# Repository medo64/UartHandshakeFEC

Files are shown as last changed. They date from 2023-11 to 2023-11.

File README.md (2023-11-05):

[UART w/Handshake Framework Expansion Card](https://medo64.com/uarthandshakefec/)
=================================================================================

This Framework laptop expansion card will show up on your system as a serial
device and allow for a non-isolated serial UART communication up to 3 Mbaud
baud rate with all handshake signals exposed.

Please note that this card is not using RS-232 but TTL (either 3.3V or 5V)
voltage levels (depending on the solder-jumper position).

## UART Pinout

To connect to this board, one has to use a 7-pin JST XH connector. The following
table represents the pinout, pin 1 being on the left as looking into the
expansion card.

| # | Ref  | Description |
|--:|:----:|---|
| 1 | CTS# | Clear To Send Control Input |
| 2 | DSR# | Data Set Ready Control Input |
| 3 | RXD  | Receiving  Data Input. |
| 4 | GND  | Ground supply |
| 5 | TXD  | Transmit Data Output |
| 6 | DTR# | Data Terminal Ready Control Output |
| 7 | RTS# | Request to Send Control Output |

As power consumption is low, wires can be almost any AWG. I would recommend
using 24 AWG wire 0.25 mm² as they allow for greater compatibility with other
connectors.

## Supported Speeds

This board employs the FT232R as its UART chip, and consequently, it supports
all the baud rates this chip [can handle](https://ftdichip.com/Documents/AppNotes/AN232B-05_BaudRates.pdf).
The table below lists the standard baud rates.

| Baud rate | Actual | Error | Divisor |
|---:|---:|---:|---:|
| 300 | 300 | 0.00% |  10000.000 |
| 600 | 600 | 0.00% | 5000.000 |
| 1,200 | 1,200 | 0.00% | 2500.000 |
| 1,800 | 1,800 | 0.00% | 1666.625 |
| 2,400 | 2,400 | 0.00% | 1250.000 |
| 4,800 | 4,800 | 0.00% | 625.000 |
| 7,200 | 7,201 | 0.01% | 416.625 |
| 9,600 | 9,600 | 0.00% | 312.500 |
| 14,400 | 14,406 | 0.04% | 208.250 |
| 19,200 | 19,200 | 0.00% | 156.250 |
| 28,800 | 28,812 | 0.04% | 104.125 |
| 38,400 | 38,400 | 0.00% | 78.125 |
| 57,600 | 57,692 | 0.16% | 52.000 |
| 115,200 | 115,385 | 0.16% | 26.000 |
| 230,400 | 230,769 | 0.16% | 13.000 |
| 460,800 | 461,538 | 0.16% | 6.500 |
| 921,600 | 923,077 | 0.16% | 3.250 |
| 1,000,000 | 1,000,000 | 0.00% | 3.000 |

While the UART chip does support baud rates up to 3 Mbaud, granularity of such
rates is severely limited.

---
*You can check my blog and other projects at [www.medo64.com](https://www.medo64.com/electronics/).*

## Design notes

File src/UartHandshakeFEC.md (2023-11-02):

### UartHandshakeFEC Parts

|  # | Part | RefDes  | Preferred Part Number |
|---:|---|---|---|
|  1 | C 10nF X7R 16V (0805) | C1 | 399-17617-1-ND |
|  2 | C 100nF X7R 16V (0805) | C2-C3 | 478-5311-1-ND |
|  1 | C 4.7uF X5R 16V (0805) | C4 | 1276-1244-1-ND |
|  3 | D TVS 5V SM05T1G (SOT23-3) | D1-D3 | SM05T1GOSCT-ND |
|  2 | DS LED (0805) | DS1-DS2 | 475-1415-1-ND |
|  1 | J JST XH Vertical (7w) | J1 | 455-B7B-XH-A-ND |
|  1 | L Ferrite 600R@100Mhz | L1 | 240-2390-1-ND |
|  2 | R 1K 0.125W (0805) | R1-R2 | RMCF0805FT1K00CT-ND |
|  1 | R 5.1K 0.125W (0805) | R3 | RMCF0805FT5K10CT-ND |
|  1 | U Transciever Uart FT232R (SSOP-28) | U1 | 768-FT232RNL-TUBE-ND |

#### Board Size

| | Dimensions | Area | Thickness |
|---|---|---|---|
| PCB |  24.0 x 27.9 mm | 1.1 in² | 0.8 mm |

#### FTDI Configuration

| Setting | Value  |
|---|---|
| CBUS0 | TXLED# |
| CBUS1 | RXLED# |
| CBUS2 | TXDEN  |
| CBUS3 | PWREN# |
| CBUS4 | SLEEP# |

#### Power

| Property | Value  |
|---|---:|
| Voltage  | 5 V |
| Current  |  90 mA |

#### Jumpers

##### 3V3

This jumper has to be bridged for operation in 3.3V. If this jumper is bridged,
5V jumper MUST NOT be bridged too.

##### 5V

This jumper has to be bridged for operation in 5V. If this jumper is bridged,
3.3V jumper MUST NOT be bridged too.

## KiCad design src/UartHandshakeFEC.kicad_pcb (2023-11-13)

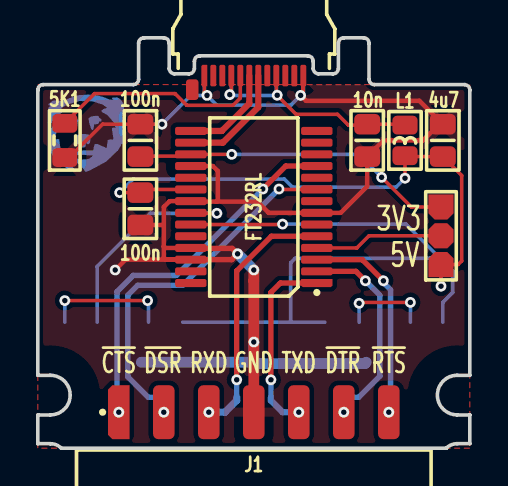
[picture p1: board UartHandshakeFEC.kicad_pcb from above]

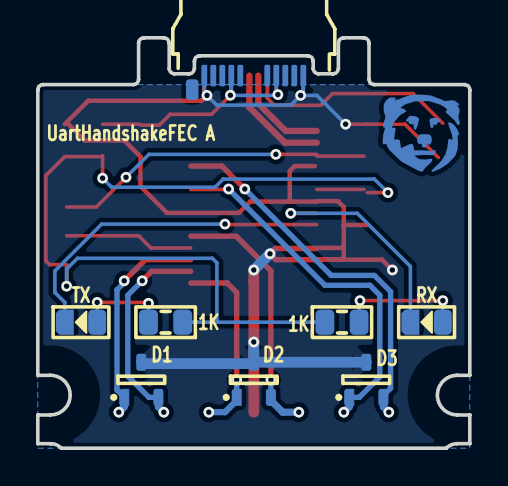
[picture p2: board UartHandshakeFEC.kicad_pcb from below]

Board: 2 copper layers, 24.0 x 22.8 mm, 18 parts (8 on the bottom side), 18 nets.

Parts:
C1: 10n; C (0805)
C2, C3: 100n; C (0805)
C4: 4u7; C (0805)
D1, D2, D3: SM05T1G; D TVS SM05T1G (SOT23-3)
DS1: RX; DS (0805)
DS2: TX; DS (0805)
ICON: Medo64; ICON Medo64
J1: B7B-XH-A; J JST XH Edge [UART] (7w)
JP1: Jumper; JP Dual (1205)
L1: 600R; L (0805)
P1: 105444-0001; P USB C 3.2 Edge (24w)
R1, R2: 1K; R (0805)
R3: 5K1; R (0805)
U1: FT232RL; U Transciever UART FT232RL (SSOP-28)

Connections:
3V3: C3.2, JP1.3, U1.17
5V: C2.2, C4.2, JP1.1, L1.1, R1.1, R2.1, U1.20
A_CC: P1.A5, R3.2
CTS#: D3.2, J1.1, U1.11
DSR#: D3.1, J1.2, U1.9
DTR#: D1.2, J1.6, U1.2
GND: C1.1, C2.1, C3.1, C4.1, D1.3, D2.3, D3.3, J1.4, P1.A1, P1.A12, P1.B01, P1.B12, R3.1, U1.7, U1.18, U1.21, U1.25, U1.26
LED_RXD: DS1.1, U1.22
LED_RXD': DS1.2, R1.2
LED_TXD: DS2.1, U1.23
LED_TXD': DS2.2, R2.2
RTS#: D1.1, J1.7, U1.3
RXD: D2.2, J1.3, U1.5
TXD: D2.1, J1.5, U1.1
USB_DM: P1.A7, U1.16
USB_DP: P1.A6, U1.15
USB_Vin: C1.2, L1.2, P1.A4, P1.A9, P1.B04, P1.B09
Vio: JP1.2, U1.4

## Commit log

2023-11-05 Updated pinout to match cisco-style pin order
    [UartHandshakeFEC.kicad_pcb]
2023-11-13 Refactoring LEDs to bottom
    [UartHandshakeFEC.kicad_pcb]
